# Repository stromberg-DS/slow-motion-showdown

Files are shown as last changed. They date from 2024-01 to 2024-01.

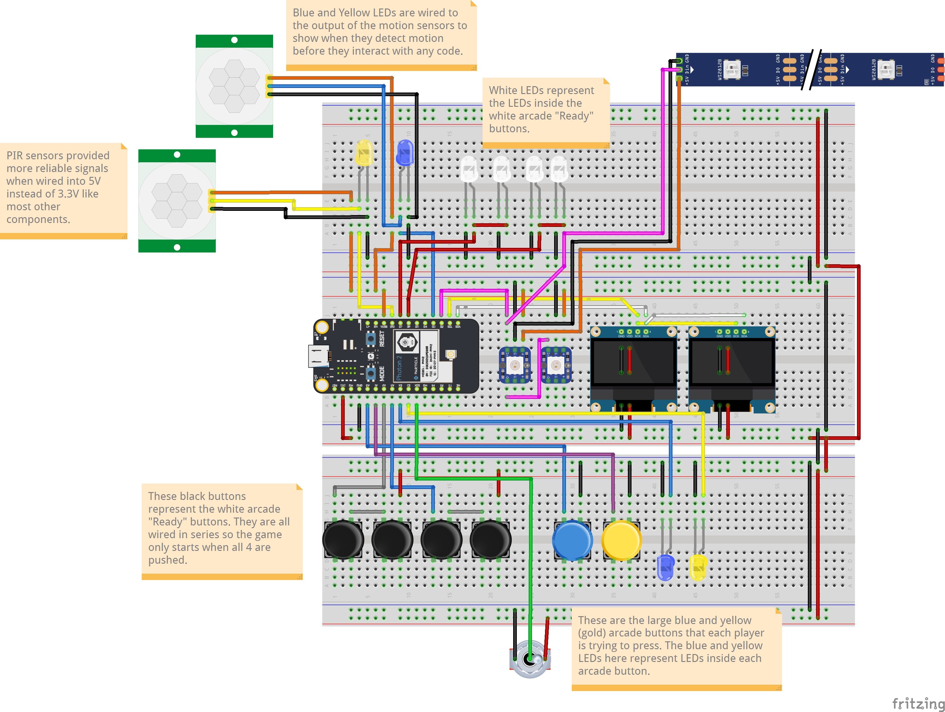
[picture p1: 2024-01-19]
SlowMotionShowdown_bb.jpg

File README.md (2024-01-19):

# slow-motion-showdown
Daniel Stromberg

Slow Motion Showdown is simple 2-player game where you try to press your button before your opponent
BUT, you cannot set off your motion detector in the process.

This game is simple, two players each have a large button in front of them that they are trying to
press before the other. Facing towards each player's button is a motion sensor. If you hit your
button, you win the round (and lots of points), but if you set off your motion detector, you end
the round (and give your opponent points).

The game is run on a Particle Photon 2 that detects the button presses and motion sensor inputs. 
The Photon 2 lights up the arcade buttons as well as edge-lighting the acrylic wall to provide
feedback to the players. Each player has a small OLED screen that gives them information about
what to do.

The game has an optional manual smart room controller mode that is activated with a toggle switch.
When switched, the attached encoder can change the color and brightness of the Hue bulbs in 
the room.

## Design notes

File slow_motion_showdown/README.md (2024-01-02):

# slow_motion_showdown

This firmware project was created using [Particle Developer Tools](https://www.particle.io/developer-tools/) and is compatible with all [Particle Devices](https://www.particle.io/devices/).

Feel free to replace this README.md file with your own content, or keep it for reference.

## Table of Contents
- [Introduction](#introduction)
- [Prerequisites To Use This Template](#prerequisites-to-use-this-repository)
- [Getting Started](#getting-started)
- [Particle Firmware At A Glance](#particle-firmware-at-a-glance)
  - [Logging](#logging)
  - [Setup and Loop](#setup-and-loop)
  - [Delays and Timing](#delays-and-timing)
  - [Testing and Debugging](#testing-and-debugging)
  - [GitHub Actions (CI/CD)](#github-actions-cicd)
  - [OTA](#ota)
- [Support and Feedback](#support-and-feedback)
- [Version](#version)

## Introduction

For an in-depth understanding of this project template, please refer to our [documentation](https://docs.particle.io/firmware/best-practices/firmware-template/).

## Prerequisites To Use This Repository

To use this software/firmware on a device, you'll need:

- A [Particle Device](https://www.particle.io/devices/).
- Windows/Mac/Linux for building the software and flashing it to a device.
- [Particle Development Tools](https://docs.particle.io/getting-started/developer-tools/developer-tools/) installed and set up on your computer.
- Optionally, a nice cup of tea (and perhaps a biscuit).

## Getting Started

1. While not essential, we recommend running the [device setup process](https://setup.particle.io/) on your Particle device first. This ensures your device's firmware is up-to-date and you have a solid baseline to start from.

2. If you haven't already, open this project in Visual Studio Code (File -> Open Folder). Then [compile and flash](https://docs.particle.io/getting-started/developer-tools/workbench/#cloud-build-and-flash) your device. Ensure your device's USB port is connected to your computer.

3. Verify the device's operation by monitoring its logging output:
    - In Visual Studio Code with the Particle Plugin, open the [command palette](https://docs.particle.io/getting-started/developer-tools/workbench/#particle-commands) and choose "Particle: Serial Monitor".
    - Or, using the Particle CLI, execute:
    ```
    particle serial monitor --follow
    ```

4. Uncomment the code at the bottom of the cpp file in your src directory to publish to the Particle Cloud! Login to console.particle.io to view your devices events in real time.

5. Customize this project! For firmware details, see [Particle firmware](https://docs.particle.io/reference/device-os/api/introduction/getting-started/). For information on the project's directory structure, visit [this link](https://docs.particle.io/firmware/best-practices/firmware-template/#project-overview).

## Particle Firmware At A Glance

### Logging

The firmware includes a [logging library](https://docs.particle.io/reference/device-os/api/logging/logger-class/). You can display messages at different levels and filter them:

```
Log.trace("This is trace message");
Log.info("This is info message");
Log.warn("This is warn message");
Log.error("This is error message");
```

### Setup and Loop

Particle projects originate from the Wiring/Processing framework, which is based on C++. Typically, one-time setup functions are placed in `setup()`, and the main application runs from the `loop()` function.

For advanced scenarios, explore our [threading support](https://docs.particle.io/firmware/software-design/threading-explainer/).

### Delays and Timing

By default, the setup() and loop() functions are blocking whilst they run, meaning that if you put in a delay, your entire application will wait for that delay to finish before anything else can run. 

For techniques that allow you to run multiple tasks in parallel without creating threads, checkout the code example [here](https://docs.particle.io/firmware/best-practices/firmware-template/).

(Note: Although using `delay()` isn't recommended for best practices, it's acceptable for testing.)

### Testing and Debugging

For firmware testing and debugging guidance, check [this documentation](https://docs.particle.io/troubleshooting/guides/build-tools-troubleshooting/debugging-firmware-builds/).

### GitHub Actions (CI/CD)

This project provides a YAML file for GitHub, automating firmware compilation whenever changes are pushed. More details on [Particle GitHub Actions](https://docs.particle.io/firmware/best-practices/github-actions/) are available.

### OTA

To learn how to utilize Particle's OTA service for device updates, consult [this documentation](https://docs.particle.io/getting-started/cloud/ota-updates/).

Test OTA with the 'Particle: Cloud Flash' command in Visual Studio Code or the CLI command 'particle flash'!

This firmware supports binary assets in OTA packages, allowing the inclusion of audio, images, configurations, and external microcontroller firmware. More details are [here](https://docs.particle.io/reference/device-os/api/asset-ota/asset-ota/).

## Support and Feedback

For support or feedback on this template or any Particle products, please join our [community](https://community.particle.io)!

## Version

Template version 1.0.2

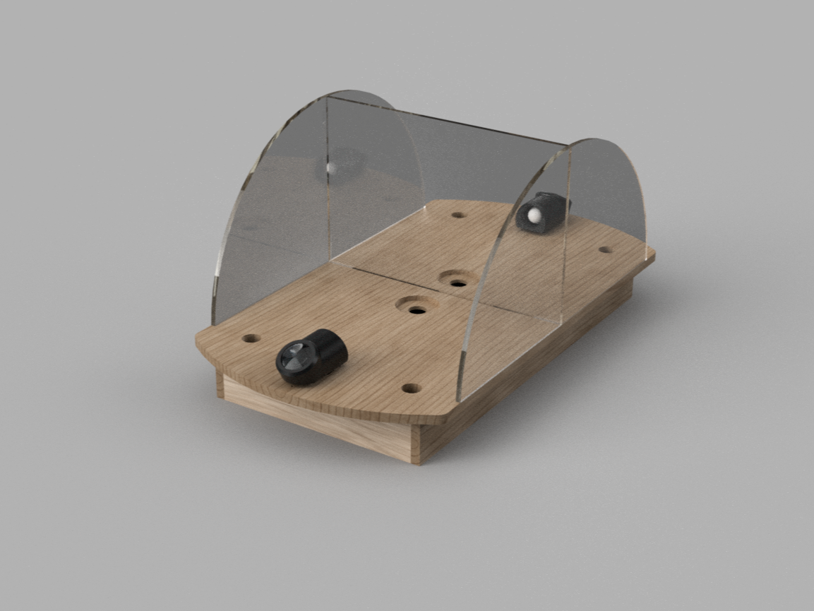
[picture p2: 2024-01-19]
GameBoardRender.png

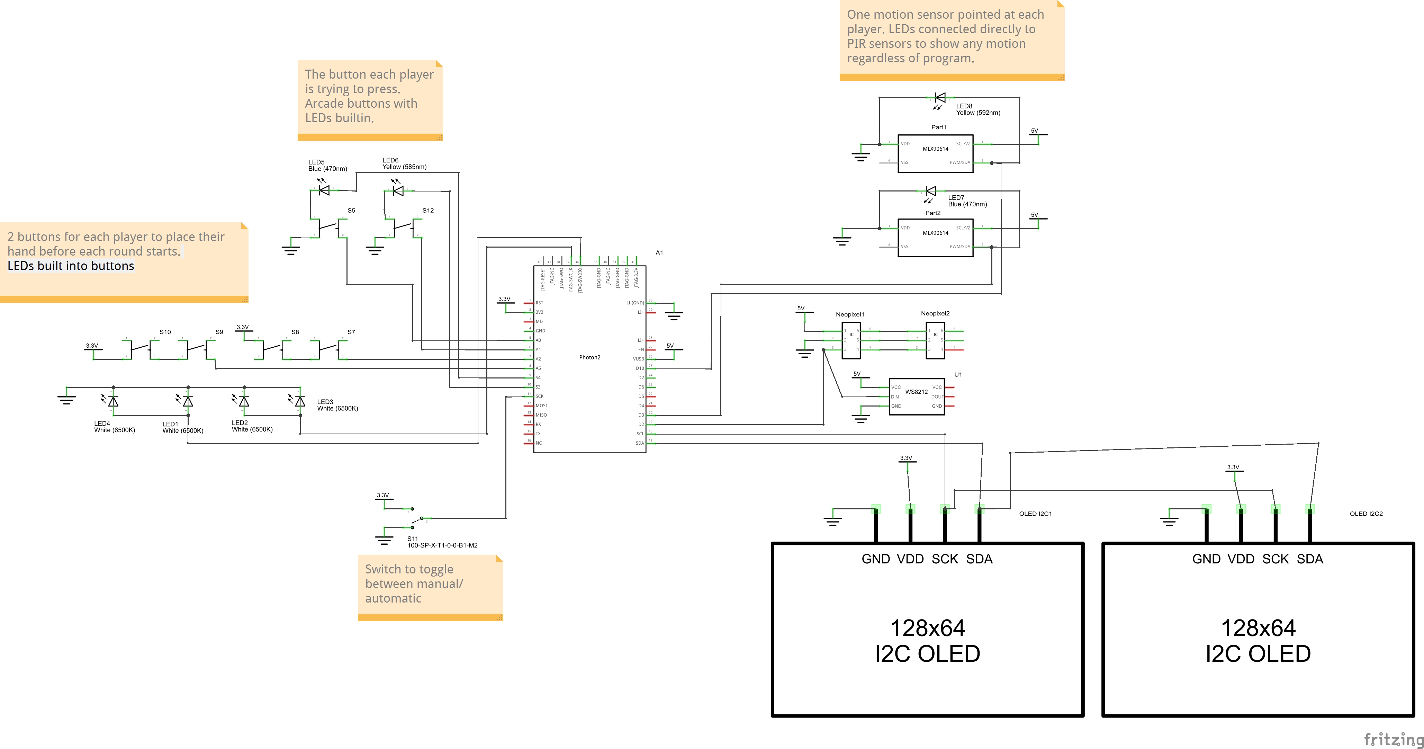
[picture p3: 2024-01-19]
SlowMotionShowdown_schem.jpg

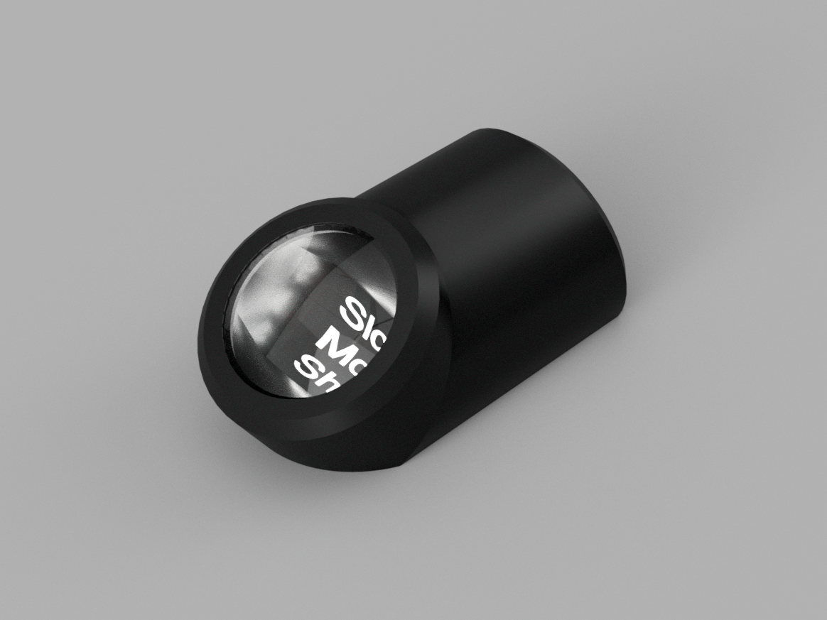
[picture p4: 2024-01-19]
PIR_OLED_Mount_Render.png

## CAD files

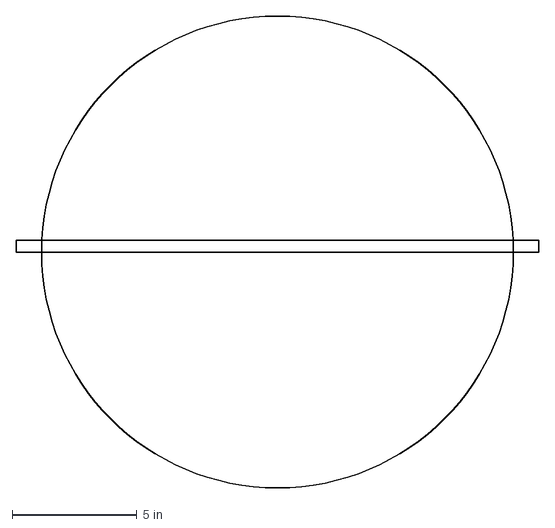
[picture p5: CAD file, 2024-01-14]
DXF Files/SideFullCircle.dxf
21.0 x 18.9 in

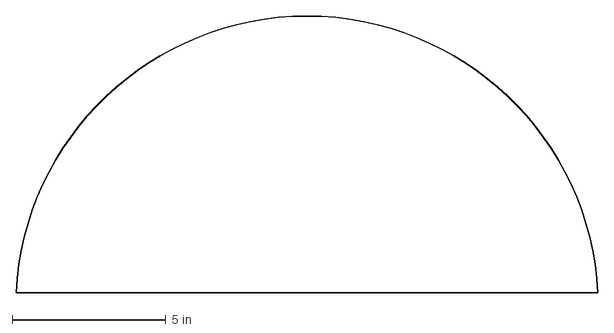
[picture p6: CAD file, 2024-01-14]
DXF Files/AcrylicWall2x.dxf
18.9 x 9.00 in

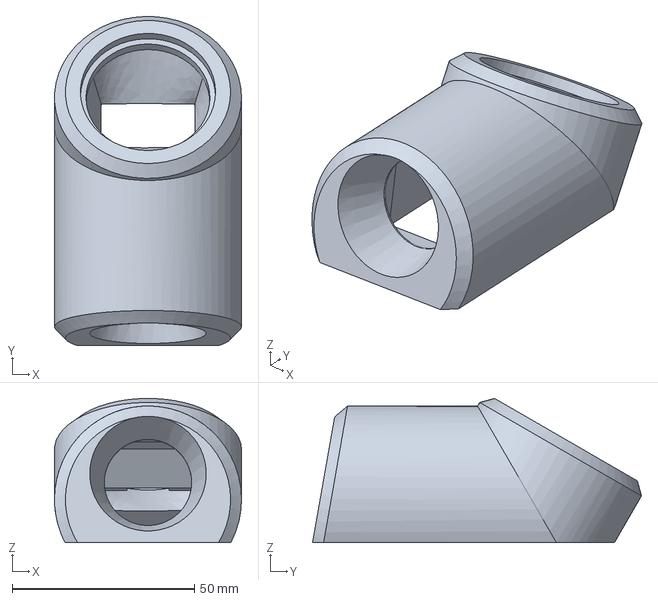
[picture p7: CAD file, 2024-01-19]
PIR_OLED_Housing.step
51.4 x 90.4 x 39.6 mm

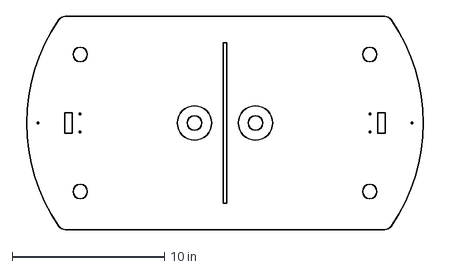
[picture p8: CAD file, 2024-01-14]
DXF Files/TableTop.dxf
27.4 x 14.0 in

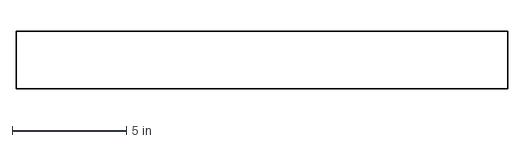
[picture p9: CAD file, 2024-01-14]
DXF Files/BaseSide2x.dxf
21.5 x 2.50 in

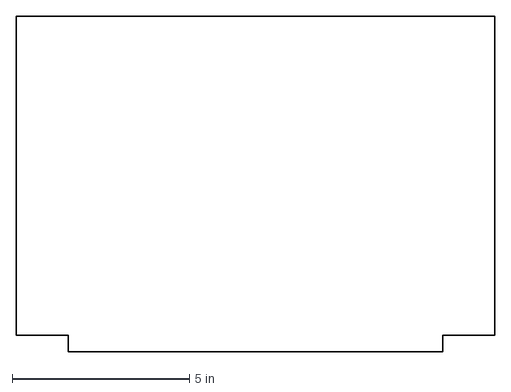
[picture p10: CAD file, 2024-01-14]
DXF Files/AcrylicBarrier.dxf
13.5 x 9.47 in

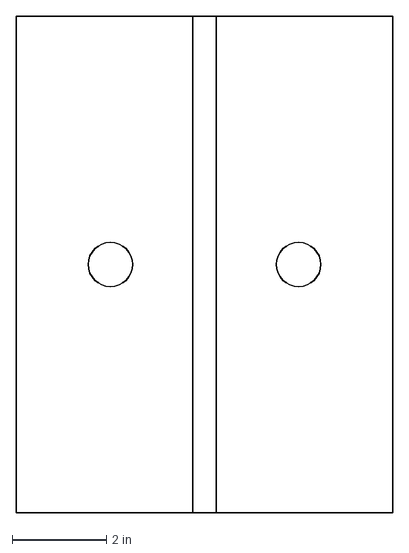
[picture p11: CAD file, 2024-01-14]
DXF Files/LEDSupport.dxf
8.00 x 10.6 in

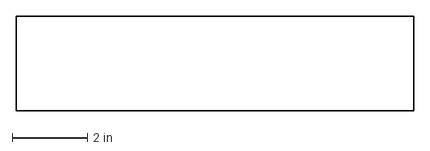
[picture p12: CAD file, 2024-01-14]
DXF Files/BaseFront2x.dxf
10.6 x 2.50 in

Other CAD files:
PIR_OLED_Housing.stl

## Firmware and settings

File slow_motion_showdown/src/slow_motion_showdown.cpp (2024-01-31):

/* 
 * Project: Slow Motion Showdown
 * Description: 2 Person game where each person tries to press their button first.
 *              The catch is each person has a motion detector aimed at their button.
 *              If they set off their motion detector, they end the round and give their opponent a point.
 *              The game doubles as a smart controller, changing the lights of the
 *              room when a player wins or loses.
 * Author: Daniel Stromberg
 * Date: 12/15/23 
*/

#include "Particle.h"
#include <IoTClassroom_CNM.h>
#include <Encoder.h>
#include <Adafruit_GFX.h>
#include <Adafruit_SSD1306.h>
#include <neopixel.h>


const int BULBS[] = {5, 3, 1, 2, 4, 6};     //bulb numbers - [0] is my testing bulb
const int MYWEMO[] = {4, 2, 3, 5, 1};     //outlet numbers - [0] is my testing outlet
const int READYBUTTONPINP1 = A2;
const int READYBUTTONPINP2 = A5;
const int P1BUTTONPIN = A1;
const int P2BUTTONPIN = A0;
const int P1MOTIONPIN = D10;
const int P2MOTIONPIN = D3;
const int AUTOMODEPIN = D17;                //Labeled S2, SCK on the Photon2
const int READYLEDPINS[] = {D7, D6};
const int PLAYERLEDS [] = {D19, D18};
const int OLED_RESET = -1;
const int PIXELCOUNT = 15;
const int WAITING = 0;
const int PLAYING = 1;
const int NOWINNER = 2;
const int WINNER = 3;
const int COUNTINGDOWN = 4;
const int ENCODERMAX = 80;
const int SPEAKERSWITCHPIN = D8;


//CHANGE BELOW CONSTANTS DEPENDING ON Setup
const int numBulbsToUse = 1;    //1-6 bulbs
const int numOutletsToUse = 2;  //1-5 outlets
const bool isWifiOn = false;     //set to false and disable manual SYSTEM_MODE if no wifi
const bool USEHUEBULBS = false;
// SYSTEM_MODE(MANUAL);
SYSTEM_MODE(SEMI_AUTOMATIC);    

SYSTEM_THREAD(ENABLED);

Adafruit_SSD1306 p1OLED(OLED_RESET);
Adafruit_SSD1306 p2OLED(OLED_RESET);
Adafruit_NeoPixel pixel(PIXELCOUNT, SPI1, WS2812B);
Button readyButtonP1(READYBUTTONPINP1);
Button readyButtonP2(READYBUTTONPINP2);
Button player1Button(P1BUTTONPIN);
Button player2Button(P2BUTTONPIN);
Button p1Motion(P1MOTIONPIN);
Button p2Motion(P2MOTIONPIN);
Button autoModeSwitch(AUTOMODEPIN);
Encoder myEnc(D4, D5);
Button encoderButton(D15);          //also labeled MO, S0


int currentMillis;
int previousMillis;
int gameMode;
int p1Score = 0;
int p2Score = 0;
int noWinTimer = 0;
int countdownStart = 0;
int loser = 0;


//Maual Mode variables
int position;
int hueManualColor = 0;
int hueManualBrightness = 100;
bool isSettingColor = true;
bool isFirstManualRun = true;
int lastHueUpdate;


void waitingForPlayers();
void gameOn();
void noWin();
void turnOnOffReadyLEDs(bool onOff);
void showScore();
void countDown();
void gameStartup();
void lightUpBulbs(bool _onOff, int _color, int _brightness);
void turnOnOffWemoSwitches(bool _onOff);
void lightLEDStrip( int _color, bool _onOff = true, int _count = PIXELCOUNT);

void setup() {
    Serial.begin(9600);
    waitFor(Serial.isConnected, 10000);


    //Setup Wifi only if we need it.
    if (isWifiOn){
        WiFi.on();
        WiFi.clearCredentials();
        WiFi.setCredentials("IoTNetwork");
        WiFi.connect();
        while (WiFi.connecting())
        {
            Serial.printf("."); 
        }
        Serial.printf("\n\n");
    }

    p1OLED.begin(SSD1306_SWITCHCAPVCC, 0x3D);
    p1OLED.clearDisplay();
    p1OLED.setTextColor(WHITE);
    p1OLED.setTextSize(2);
    p1OLED.display();

    p2OLED.begin(SSD1306_SWITCHCAPVCC, 0x3C);
    p2OLED.clearDisplay();
    p2OLED.setTextColor(WHITE);
    p2OLED.setTextSize(2);
    p2OLED.display();

    // gameStartup();

    position = myEnc.read();

    pixel.begin();
    pixel.setBrightness(30); 
    lightLEDStrip(0x00FFFF);
    // pixel.setPixelColor(0, 0,255,0);
    // pixel.setPixelColor(1, 0,255,0);
    // pixel.show();
    delay(3000);
    pixel.clear();
    pixel.show();

    for (int i=0; i < 2; i++){
        pinMode(READYLEDPINS[i], OUTPUT);
        digitalWrite(READYLEDPINS[i], LOW);
    }

    pinMode(PLAYERLEDS[0], OUTPUT);
    pinMode(PLAYERLEDS[1], OUTPUT);
    pinMode(SPEAKERSWITCHPIN, OUTPUT);
    digitalWrite(SPEAKERSWITCHPIN, LOW);
    digitalWrite(PLAYERLEDS[0], LOW);
    digitalWrite(PLAYERLEDS[1], LOW);

    
}

void loop() {
    currentMillis = millis();
    static String hueOrBrightness = "hue";

    if(autoModeSwitch.isClicked()){         //switch high is game mode
        Serial.printf("switch flipped");
        gameStartup();
        isFirstManualRun = true;
    }

    if (autoModeSwitch.isPressed()){        //AUTO MODE (PLAYING GAME)
        switch (gameMode){
            case WAITING:
                waitingForPlayers();
                break;
            case PLAYING:
                gameOn();
                break;
            case NOWINNER:
                noWin();
                break;
            case COUNTINGDOWN:
                countDown();
        }
    }
    else {                                //MANUAL CONTROL MODE
        position = myEnc.read();
        if(isFirstManualRun){
            digitalWrite(READYLEDPINS[0], LOW);
            digitalWrite(READYLEDPINS[1], LOW);
            p1OLED.clearDisplay();
            p1OLED.setCursor(0,0);
            p1OLED.setTextSize(2);
            // p1OLED.printf("Set hue &\n");
            // p1OLED.printf("intensity\nwith\nencoder.");
            p1OLED.printf("Now\nadjusting\n");
            p1OLED.printf("%s", hueOrBrightness.c_str());
            Serial.printf("Now adjusting: %s\n", hueOrBrightness.c_str());
            p1OLED.display();
            p2OLED.display();

            isFirstManualRun = false;
        }



        if(encoderButton.isClicked()){      
            isSettingColor = !isSettingColor;
            isFirstManualRun = true;
        }

        if (position > ENCODERMAX)    {    //Cap the encoder position at the encoder max
            myEnc.write(ENCODERMAX);
            position = ENCODERMAX;
        }
        else if (position < 0)    {       //Minimum encoder position is 0
            myEnc.write(0);
            position = 0;
        }

        if(isSettingColor){
            hueManualColor = map(position, 0, ENCODERMAX, 0, 50000);
            hueOrBrightness = "hue";
        }
        else {
            hueManualBrightness = map(position, 0, ENCODERMAX, 0, 255);
            hueOrBrightness = "intensity";
        }

        if((currentMillis - lastHueUpdate) > 500){
            // setHue(BULBS[0], true, hueManualColor, hueManualBrightness, 255);
            lightUpBulbs(true, hueManualColor, hueManualBrightness);
            lastHueUpdate = currentMillis;
        }

        lightLEDStrip(0x00FFFF);
        // pixel.setPixelColor(0,0,255, 255);
        // pixel.setPixelColor(1,0,255, 255);
    }

    pixel.show();

}

//  Blinks LEDs red when someone loses
void noWin(){   
    if((currentMillis - noWinTimer) < 4000){
        p1OLED.clearDisplay();
        p1OLED.setCursor(0,0);
        p1OLED.setTextSize(4);
        if(loser ==1){
            p1OLED.printf("GOLD\nLOST");
        } else if(loser == 2){
            p1OLED.printf("BLUE\nLOST");
        }
        else{
            p1OLED.printf("ERROR");
        }
        p1OLED.display();
        p2OLED.display();
        p1OLED.setTextSize(2);
        
        if((currentMillis - noWinTimer) % 500 < 250){   //pulse red lights every 250ms
            lightLEDStrip(0xFF0000);
        }
        else{
            pixel.clear();
            pixel.show();
        }

    }
    else{
        loser = 0;
        showScore();
        lightUpBulbs(false, 0, 0);
        // setHue(BULBS[0], false, 0, 0, 0);        //turn off bulb
        gameMode = WAITING;
    }
}

//  Start the round where each player tries to press their button
void gameOn(){

    lightLEDStrip(0x00FF00);
    // pixel.setPixelColor(0,0,255,0);
    // pixel.setPixelColor(1, 0, 255, 0);
    digitalWrite(PLAYERLEDS[0], HIGH);
    digitalWrite(PLAYERLEDS[1], HIGH);


    //End the game if either player triggers their motion sensor.
    if (p1Motion.isClicked()){          
        Serial.printf("P1 LOSER\n");
        loser = 1;
        p2Score++;
        turnOnOffWemoSwitches(false);
        // wemoWrite(MYWEMO[0], LOW);
        lightUpBulbs(true, HueRed, 255);
        // setHue(BULBS[0], true, HueRed, 255, 255);     //set bulb red
        noWinTimer = currentMillis;
        gameMode = NOWINNER;
    }
    if (p2Motion.isClicked()){
        loser = 2;
        Serial.printf("P2 LOSER");
        p1Score++;
        turnOnOffWemoSwitches(false);
        // wemoWrite(MYWEMO[0], LOW);
        lightUpBulbs(true, HueRed, 255);
        // setHue(BULBS[0], true, HueRed, 255, 255);     //set bulb red
        noWinTimer = currentMillis;
        gameMode = NOWINNER;
    }

    //Meanwhile, wait for each player to press their own button
    if(player1Button.isClicked()){
        lightLEDStrip(0xFFDD00);
        p1OLED.clearDisplay();
        p1OLED.setCursor(0,0);
        p1OLED.setTextSize(4);
        p1OLED.printf("GOLD\nWINS!");
        p1OLED.display();
        p2OLED.display();
        p1OLED.setTextSize(2);
        delay(1000);

        p1Score = p1Score +5;

        // pixel.setPixelColor(0,0,0,255);
        // pixel.setPixelColor(1,0,0,255);
        // pixel.show();
        showScore();
        turnOnOffWemoSwitches(false);
        // wemoWrite(MYWEMO[0], LOW);
        lightUpBulbs(true, HueYellow, 200);
        // setHue(BULBS[0], true, HueBlue, 150, 255);        //turn bulb blue
        delay(2000);
        gameMode = WAITING;
        lightUpBulbs(false, HueGreen, 150);
        // setHue(BULBS[0], false, HueGreen, 150, 255);        //turn bulb off
        
    }
    else if (player2Button.isClicked()) {
        lightLEDStrip(0x0000FF);
        p1OLED.clearDisplay();
        p1OLED.setCursor(0,0);
        p1OLED.setTextSize(4);
        p1OLED.printf("BLUE\nWINS!");
        p1OLED.display();
        p2OLED.display();
        p1OLED.setTextSize(2);
        delay(1000);

        p2Score = p2Score +5;
        // pixel.setPixelColor(0,255,255,0);
        // pixel.setPixelColor(1,255,255,0);
        // pixel.show();
        showScore();
        turnOnOffWemoSwitches(false);
        // wemoWrite(MYWEMO[0], LOW);
        lightUpBulbs(true, HueBlue, 200);
        // setHue(BULBS[0], true, HueYellow, 150, 255);        //turn bulb yellow
        delay(2000);
        gameMode = WAITING;
        lightUpBulbs(false, HueGreen, 150);
        // setHue(BULBS[0], false, HueGreen, 150, 255);        //turn bulb off
    }

}

//  Wait for players to press ready buttons while instructing them to do so.
void waitingForPlayers(){
    turnOnOffReadyLEDs(true);
    digitalWrite(PLAYERLEDS[0], LOW);
    digitalWrite(PLAYERLEDS[1], LOW);
    p1OLED.clearDisplay();
    p1OLED.setCursor(0,0);
    p1OLED.printf("Place both");
    p1OLED.printf("hands on\nthe white\nbuttons");
    p1OLED.display();
    p2OLED.display();

    lightLEDStrip(0xFF0000);
    // pixel.setPixelColor(0,255,0,0);
    // pixel.setPixelColor(1, 255, 0, 0);
    

    if (readyButtonP1.isPressed() && readyButtonP2.isPressed()){
        pixel.clear();
        pixel.show();
        turnOnOffReadyLEDs(false);

        countdownStart = currentMillis;
        gameMode = COUNTINGDOWN;        
    }
    pixel.show();
}

//  Give both players a countdown to the start of the round.
void countDown(){
    if((currentMillis - countdownStart) < 5000){
        if((currentMillis - countdownStart) < 2000){
            p1OLED.clearDisplay();
            p1OLED.setCursor(0,0);
            p1OLED.printf("Get ready\nto start\nin...");
            p1OLED.display();
            p2OLED.display();
        }
        else if((currentMillis - countdownStart) < 3000){
            p1OLED.clearDisplay();
            p1OLED.setCursor(40,0);
            p1OLED.setTextSize(9);
            p1OLED.printf("3");
            p1OLED.display();
            p2OLED.display();
        }
        else if((currentMillis - countdownStart) < 4000){
            p1OLED.clearDisplay();
            p1OLED.setCursor(40,0);
            p1OLED.printf("2");
            p1OLED.display();
            p2OLED.display();
        }
        else{
            p1OLED.clearDisplay();
            p1OLED.setCursor(40,0);
            p1OLED.printf("1");
            p1OLED.display();
            p2OLED.display();
        }
    }
    else {
        lightLEDStrip(0x00FF00);
        // pixel.setPixelColor(0, 0, 255, 0);
        // pixel.setPixelColor(1, 0, 255, 0);
        // pixel.show();
        // lightUpBulbs(false, HueGreen, 150);
        turnOnOffWemoSwitches(true);
        // wemoWrite(MYWEMO[0], HIGH);
        p1OLED.setTextSize(2);
        p1OLED.clearDisplay();
        p1OLED.display();
        p2OLED.setTextSize(2);
        p2OLED.clearDisplay();
        p2OLED.display();
        gameMode = PLAYING;
    }

}

//Turn on or off all of the ready button LEDs
void turnOnOffReadyLEDs(bool onOff){
    for (int i=0; i < 2; i++){
        digitalWrite(READYLEDPINS[i], onOff);
    }
}

//  Display the scores of the 2 players.
void showScore(){
    p1OLED.setTextSize(2);
    p2OLED.setTextSize(2);
    p1OLED.clearDisplay();
    p1OLED.setCursor(0,0);
    p1OLED.printf("Gold: %i\nBlue: %i", p1Score, p2Score);
    p1OLED.display();
    p2OLED.display();
    delay(2000);
}


//  Setup the game, displaying relevant info on OLED screens
void gameStartup(){
    p1Score = 0;
    p2Score = 0;

    p1OLED.clearDisplay();
    p1OLED.setTextColor(WHITE);
    p1OLED.setTextSize(2);
    p1OLED.display();

    p2OLED.clearDisplay();
    p2OLED.setTextColor(WHITE);
    p2OLED.setTextSize(2);
    p2OLED.display();

    p1OLED.setCursor(0, 10);
    p1OLED.printf("Slow\nMotion\nShowdown");
    p1OLED.display();
    p2OLED.display();       //This just displays the same as p1OLED. Using this to my advantage.
    delay(3000);
    
    p1OLED.clearDisplay();
    p1OLED.setCursor(10, 5);
    p1OLED.setTextSize(3);
    p1OLED.printf("Player");
    p1OLED.setCursor(10, 35);
    p1OLED.printf("1-Gold");
    p1OLED.display();
    p1OLED.setTextSize(2);

    p2OLED.clearDisplay();
    p2OLED.setCursor(10, 5);
    p2OLED.setTextSize(3);
    p2OLED.printf("Player");
    p2OLED.setCursor(10, 35);
    p2OLED.printf("2-Blue");
    p2OLED.display();
    p2OLED.setTextSize(2);

    delay(3000);

    p1OLED.clearDisplay();
    p1OLED.display();

    p2OLED.clearDisplay();
    p2OLED.display();

    lightUpBulbs(false, HueGreen, 150);
    // setHue(BULBS[0], false, HueGreen, 150, 255);   

    gameMode = WAITING;
}

//  Turn on or off up all of the Bulbs in the array.
//  Makes it easy to switch between 1 or many bulbs.
void lightUpBulbs(bool _onOff, int _color, int _brightness){
    if (USEHUEBULBS){
        for(int i=0; i< numBulbsToUse; i++){
            setHue(BULBS[i], _onOff, _color, _brightness, 255);
        }
    }
}

//  Lights up LED strips in the array, using the color and,
//  optionally, the on/off state and number of LEDs to light.
void lightLEDStrip(int _color, bool _onOff, int _count){
    if(_onOff){
        for(int i=0; i<PIXELCOUNT; i++){
            pixel.setPixelColor(i, _color);
        }
        pixel.show();
    }
    else{
        for(int i=0; i<PIXELCOUNT; i++){
            pixel.clear();
        }
        pixel.show();
    }
}

//Turns on or off all of the wemo switches in the array.
void turnOnOffWemoSwitches(bool _onOff){
    for(int i=0; i < numOutletsToUse; i++){
        wemoWrite(MYWEMO[i], _onOff);
    }
    digitalWrite(SPEAKERSWITCHPIN, _onOff);
}

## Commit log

2023-12-15 added fritzing drawing
    [SlowMotionShowdown.fzz]
2024-01-02 Added PIR sensor
2024-01-03 Updated Fritzing
    [SlowMotionShowdown.fzz]
2024-01-05 Added 2nd PIR and OLED
    [SlowMotionShowdown.fzz]
2024-01-09 Added 3D model of PIR mount
    [PIR_OLED_Housing.stl]
2024-01-09 updated housing model
    [PIR_OLED_Housing.stl]
2024-01-09 Added mounting points, tweaked screen bezel
    [PIR_OLED_Housing.stl]
2024-01-09 Added details to wiring diagram
    [SlowMotionShowdown.fzz]
2024-01-10 Shortened housing PIR barrel
    [PIR_OLED_Housing.stl]
2024-01-10 Widened barrel for more sensing
    [PIR_OLED_Housing.stl]
2024-01-12 Added auto/manual switch, split ready buttons
2024-01-14 Added CNC design and cut files, lasercutter files
    [AcrylicBarrier.dxf, AcrylicWall2x.dxf, BaseFront2x.dxf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]
2024-01-19 Updated wiring diagram
    [SlowMotionShowdown.fzz]
2024-01-19 Adjusted some UI issues
    [slow_motion_showdown.cpp]
2024-01-19 Fixed the colors that light up
    [PIR_OLED_Housing.step]
2024-01-19 Swapped Hue bulb colors for winner
    [slow_motion_showdown.cpp]
